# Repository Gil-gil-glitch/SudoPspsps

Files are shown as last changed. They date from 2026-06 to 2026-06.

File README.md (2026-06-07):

# SudoPsPsPs — Assistive Robot Cat

SudoPsPsPs is an assistive robotic cat designed to provide companionship and proactive social interaction. Using a pan-tilt head mechanism, computer vision (Intel RealSense D455), local speech processing, and a Liquid Foundation Model (LFM), the robot maintains attention on users and engages in meaningful, mood-aware conversations.

All interactions are driven by **vocal commands and natural conversation**, processed locally via Faster-Whisper, with heavy visual and LLM reasoning offloaded to a dedicated inference server.

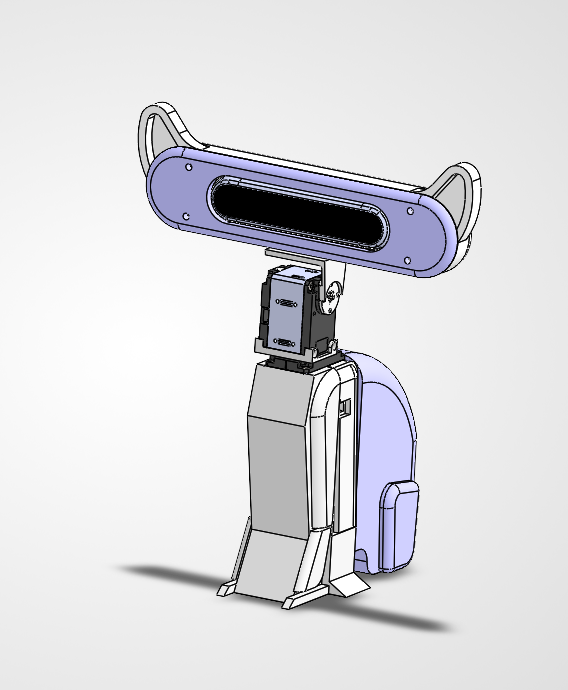
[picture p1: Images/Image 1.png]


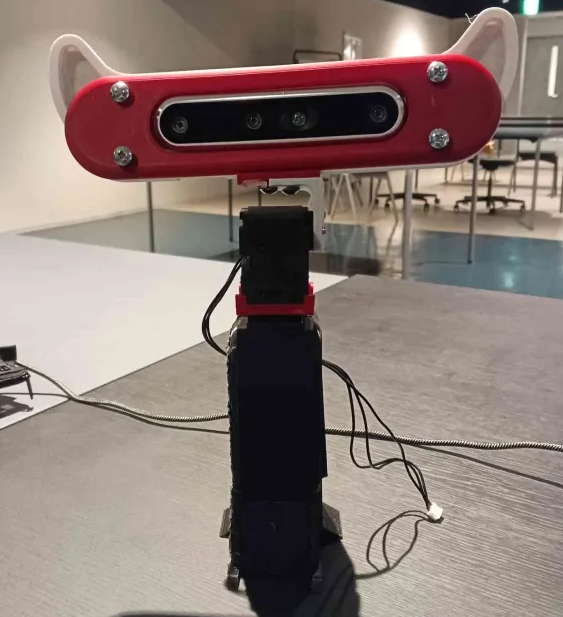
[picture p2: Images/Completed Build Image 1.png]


---

## Hardware

### Pan-Tilt Mechanism

| Component | Description |
|---|---|
| Pan Servo | Dynamixel XL430-W250-T (ID 1) |
| Tilt Servo | Dynamixel XL430-W250-T (ID 2) |
| Controller | OpenCR |
| Interface | USB Serial |
| Protocol | Dynamixel Protocol 2.0 |

### Sensor & Audio Suite

| Component | Details |
|---|---|
| Vision | Intel RealSense D455 |
| Microphone | Steinberg UR22mkII audio interface |
| Speaker | Local ALSA-routed speaker |

---

## Software Architecture

The system uses **ROS 2 (Humble)** as middleware connecting hardware control, perception, and reasoning. Two machines communicate over a dedicated Ethernet link.

| Machine | Role |
|---|---|
| **Macbook** (Inference Server) | Runs `model_server.py` and the LFM. Handles NLP, task scheduling reasoning, and vision-based VAD emotion inference. |
| **Lenovo LOQ** (Robot Host) | Runs all ROS 2 nodes. Handles hardware control (Dynamixels, RealSense), STT/TTS, image preprocessing, and the behavioral state machine. |
| **Ethernet `10.42.0.x`** | High-speed local link passing image crops and JSON payloads between the two machines. |

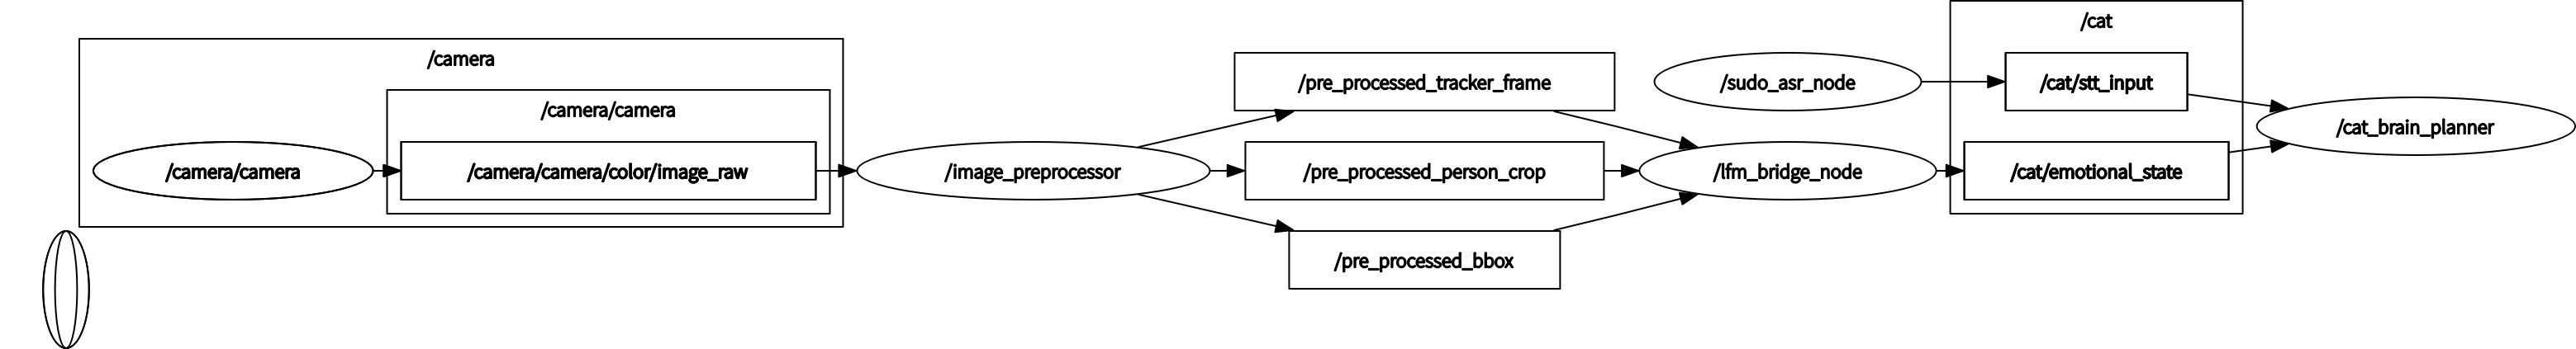
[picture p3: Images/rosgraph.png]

All the nodes, aside from cat_brain_planner and lfm_bridge_node, run on the Lenovo LOQ side while the cat_brain_planner and lfm_bridge_node acts as the interface to the Inference server hosted on the Macbook.

---

## Codebase Overview

### Hardware Control

- **`dynamixel_driver.py`** — OpenCR communication, torque enablement, and startup calibration. Converts degrees to raw Dynamixel 2.0 protocol positions.
- **`head_node.py`** — ROS 2 hardware abstraction node. Subscribes to `/head/pan_target` and `/head/tilt_target`; applies Exponential Moving Average (EMA) smoothing to motor commands.

### Vision & Tracking

- **`person_targetting_node.py`** — Core visual state machine (`SEARCHING` → `TRACKING` → `TALKING`). Uses MediaPipe Pose for bounding boxes and implements cat-like kinematics: discrete saccades, generous dead-zones, and curious idle head-tilts.
- **`image_preprocessor.py`** — Active only when locked onto a user. Crops and resizes RealSense frames (224×224 person crop, 336×336 spatial context) and publishes them for inference.

### Audio & Speech Processing

- **`stt_node.py`** — Local ASR via `faster-whisper` on GPU. Features an RMS noise threshold gate; publishes transcriptions to `/cat/stt_input`. This is the **primary trigger** for robot interaction.
- **`tts_node.py`** — Offline TTS using Piper. Subscribes to `/cat/robot_actions`, extracts `message_to_user` from JSON payloads, and routes audio to the local ALSA system.
- **`speaker_finder.py`** — PyAudio utility to enumerate hardware audio devices and identify the correct speaker index.

### AI & Reasoning

- **`lfm_bridge_node.py`** — Async bridge node. Packages cropped user images as base64 payloads and POSTs them to the Macbook vision model. Publishes Valence, Arousal, and Dominance (VAD) scores to `/cat/emotional_state`.
- **`cat_brain_planner.py`** — The cognitive core. Manages multi-turn conversation, schedule assignment, and proactive reminders. Fuses STT input with VAD emotional state to generate mood-aware suggestions (e.g., suggesting rest if valence is low).
- **`train_lora.py`** — Standalone QLoRA fine-tuning script for the LFM2 vision-language model using HuggingFace `peft` and `trl`. Aligns the robot's persona and reasoning with the Sudo dataset.

---

## Setup & Launch

### Network Configuration

Connect both machines over Ethernet and assign static IPs:

| Machine | IP |
|---|----|
| Macbook (Inference Server) | `10.42.0.2` |
| Lenovo LOQ (Robot Host) | `10.42.0.1` |

---

### 1. Macbook — Start the Inference Server

```bash
python model_server.py --host 0.0.0.0 --port 8000
```

---

### 2. Lenovo LOQ — Source the Workspace

```bash
source /opt/ros/humble/setup.bash
source ~/ri_one_master_ws/install/setup.bash
```

---

### 3. Launch Hardware Drivers

```bash
ros2 launch realsense2_camera rs_launch.py
ros2 run sudo_pspsps head_node
```

---

### 4. Spin Up Perception & Audio Nodes

Open separate terminals for each:

```bash
ros2 run sudo_pspsps person_targetting_node
ros2 run sudo_pspsps image_preprocessor
ros2 run sudo_pspsps stt_node
ros2 run sudo_pspsps tts_node
```

---

### 5. Start Bridging & Planning Nodes

```bash
ros2 run sudo_pspsps lfm_bridge_node
ros2 run sudo_pspsps cat_brain_planner
```

---

### Manual Head Test

To verify servo movement before launching the planner:

```bash
ros2 topic pub --once /head/pan_target std_msgs/msg/Float32 "{data: 30.0}"
```

---

## Current Status

| Feature | Status |
|---|---|
| Dynamixel communication & ROS 2 head node | Complete |
| Cat-like saccade motion profiling | Complete |
| MediaPipe person tracking & targeting | Complete |
| Local Whisper STT & Piper TTS | Complete |
| Async LFM HTTP bridging to Macbook | Complete |
| VAD emotional state assessment from RealSense crops | Complete |
| Conversational task planning & proactive mood suggestions | Complete |
| QLoRA training pipeline for LFM persona alignment | Complete |

---

## Team Vision

SudoPsPsPs aims to be a robotic companion capable of maintaining attention, understanding conversational context, and proactively checking in on users — not by reacting to physical triggers, but by acting as a supportive social presence guided by vocal input, multimodal perception, and advanced LLM reasoning.

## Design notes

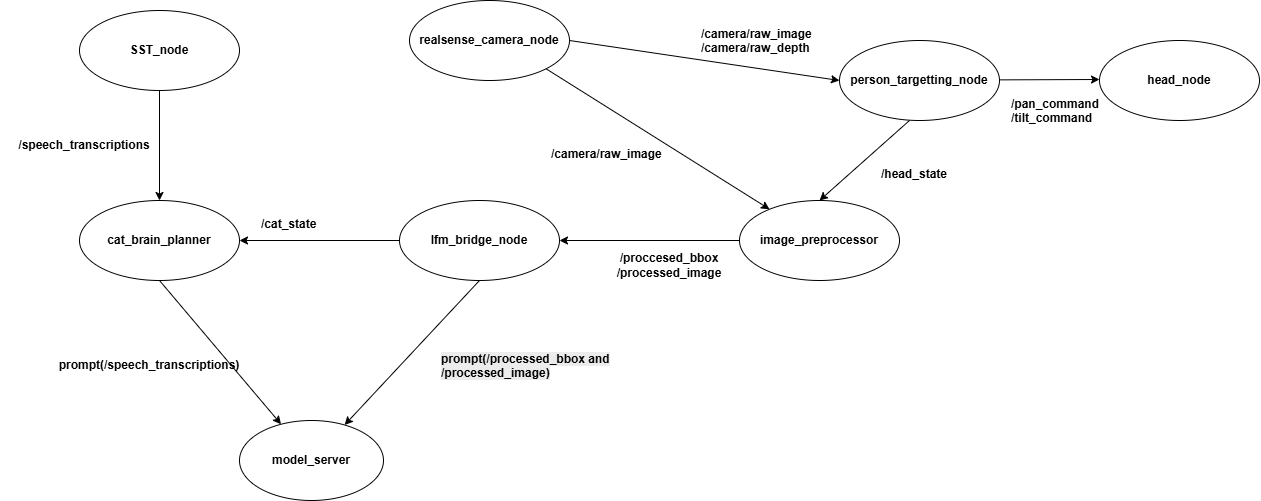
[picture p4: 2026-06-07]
Images/SudoPsPsPsArchitecture.drawio.png

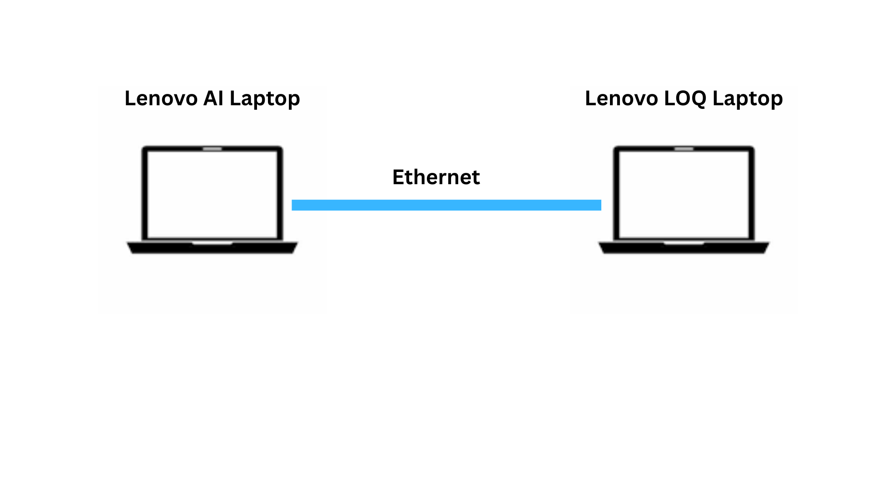
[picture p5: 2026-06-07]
Images/Communication Diagram.png

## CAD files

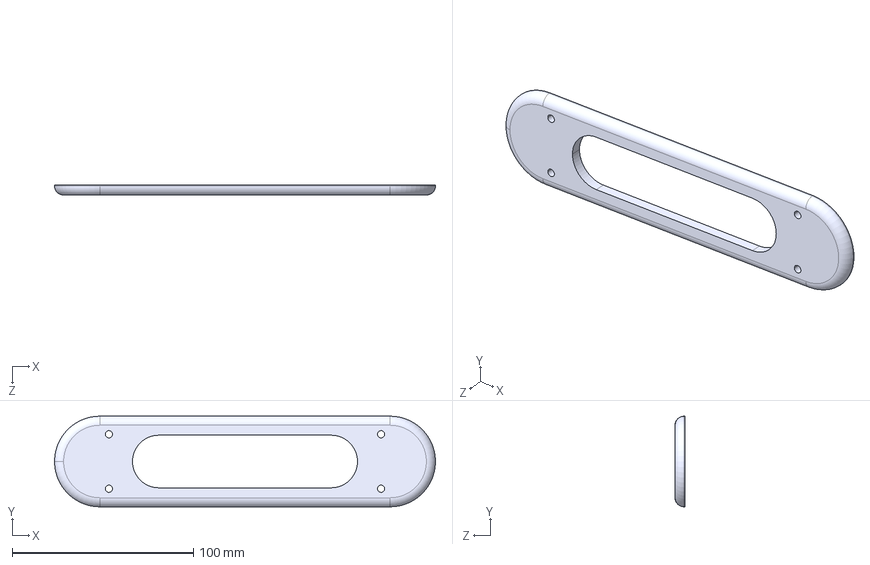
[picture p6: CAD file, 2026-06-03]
3d-Models/Step files/1. Head Front.STEP
210.0 x 50.0 x 5.50 mm

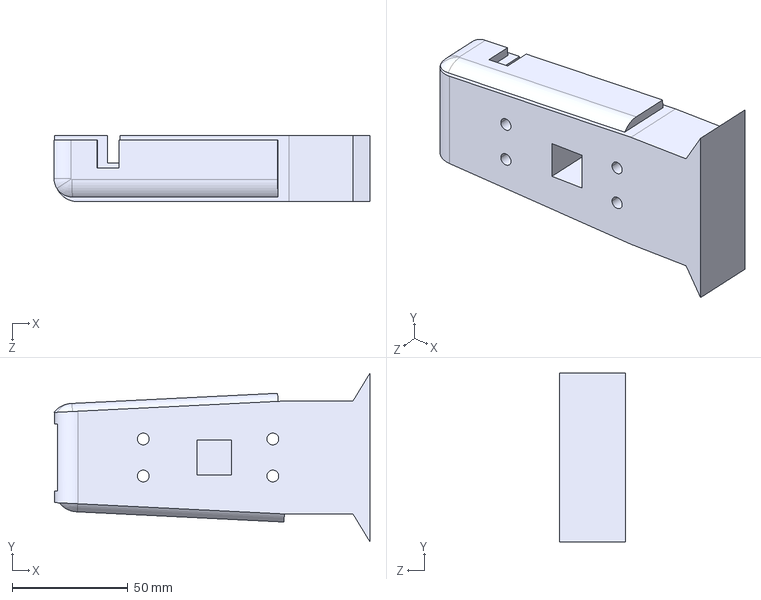
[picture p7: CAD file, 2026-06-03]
3d-Models/Step files/4. Body Back.STEP
136.6 x 73.0 x 28.6 mm

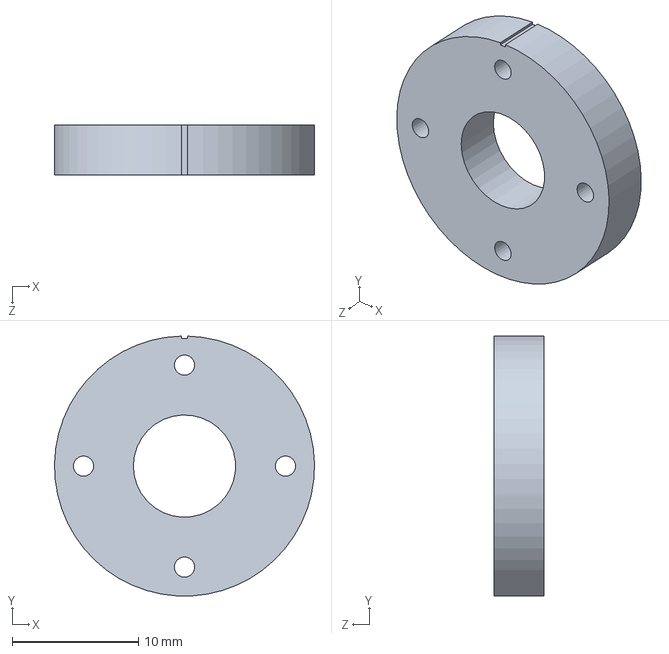
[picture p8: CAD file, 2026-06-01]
3d-Models/Solidworks/5. Neck.SLDPRT
20.6 x 20.6 x 4.00 mm

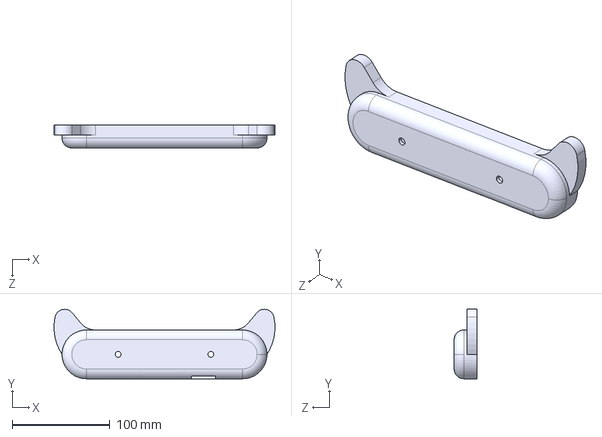
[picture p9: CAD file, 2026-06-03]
3d-Models/Step files/2. Head Back.STEP
226.5 x 71.3 x 23.4 mm

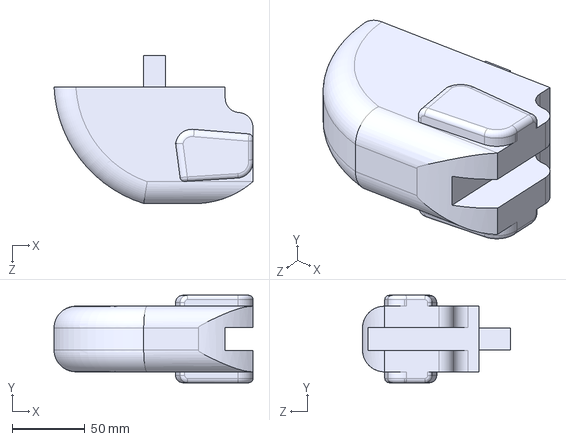
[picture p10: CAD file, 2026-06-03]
3d-Models/Step files/Tail End.STEP
136.4 x 60.0 x 101.5 mm

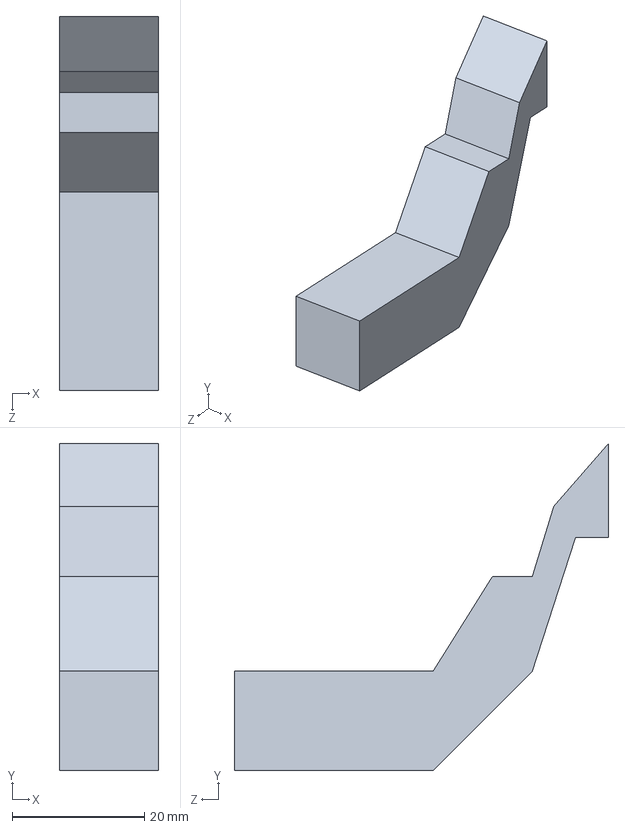
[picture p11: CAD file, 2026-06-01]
3d-Models/Solidworks/6. Tail.SLDPRT
15.0 x 49.4 x 56.5 mm

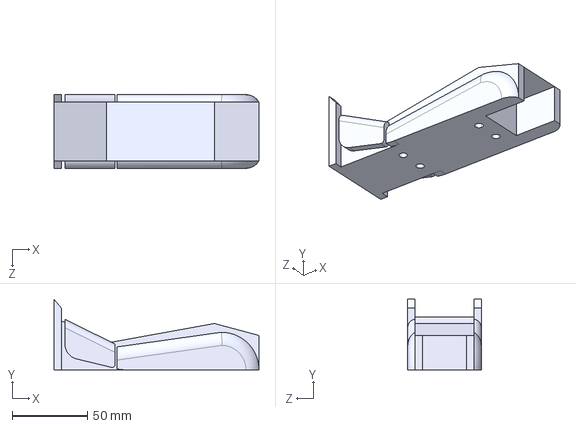
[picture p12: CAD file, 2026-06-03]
3d-Models/Step files/3. Body Front.STEP
136.3 x 47.0 x 49.0 mm

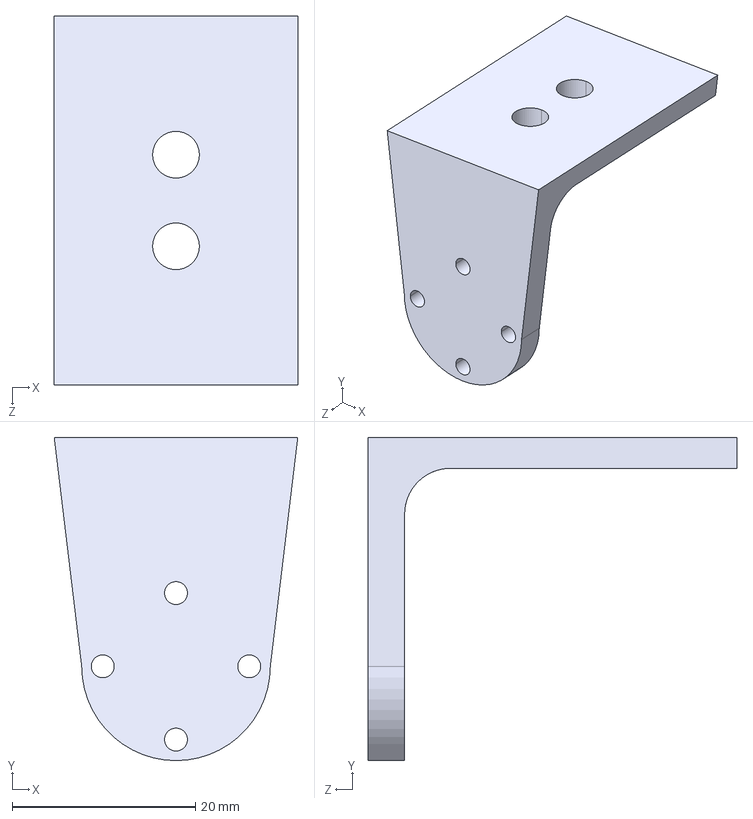
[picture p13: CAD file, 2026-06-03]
3d-Models/Step files/6. Top Motor Mount^Backv2.STEP
26.6 x 35.3 x 40.3 mm

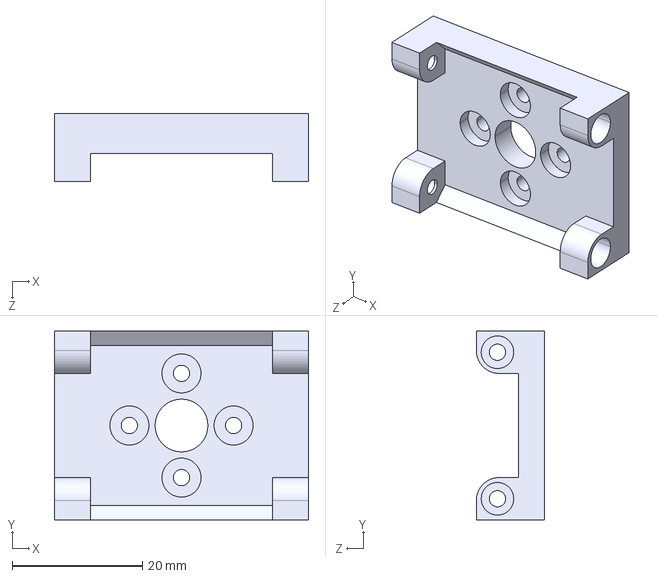
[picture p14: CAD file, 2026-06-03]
3d-Models/Step files/5. Bottom Motor Mount.STEP
39.0 x 29.0 x 10.5 mm

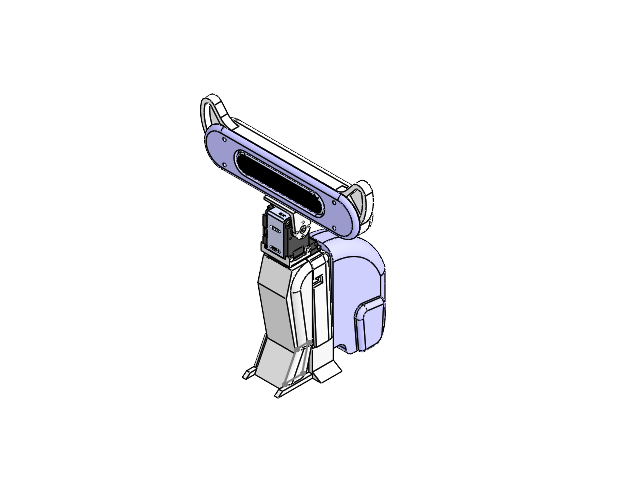
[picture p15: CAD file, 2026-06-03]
3d-Models/Solidworks/Full Body v2.SLDASM
XL430_W250_T x 2
3. Body Front
4. Body Back
Tail End
5. Bottom Motor Mount
6. Top Motor Mount^Back
Intel Realsense D455
1. Head Front
2. Head Back

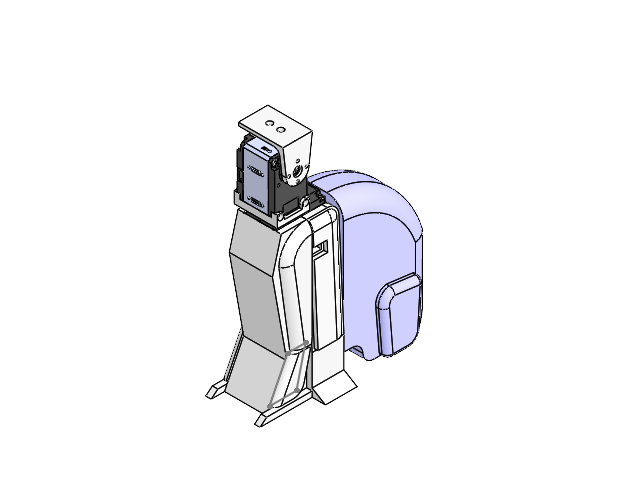
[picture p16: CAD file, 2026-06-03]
3d-Models/Solidworks/Back.SLDASM
XL430_W250_T x 2
3. Body Front
4. Body Back
Tail End
5. Bottom Motor Mount
6. Top Motor Mount^Back

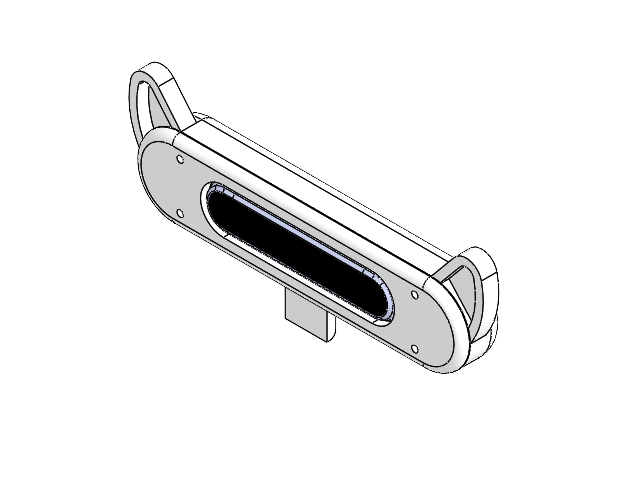
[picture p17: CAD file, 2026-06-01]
3d-Models/Solidworks/Head.SLDASM
Intel Realsense D455
1. Head Front
2. Head Back

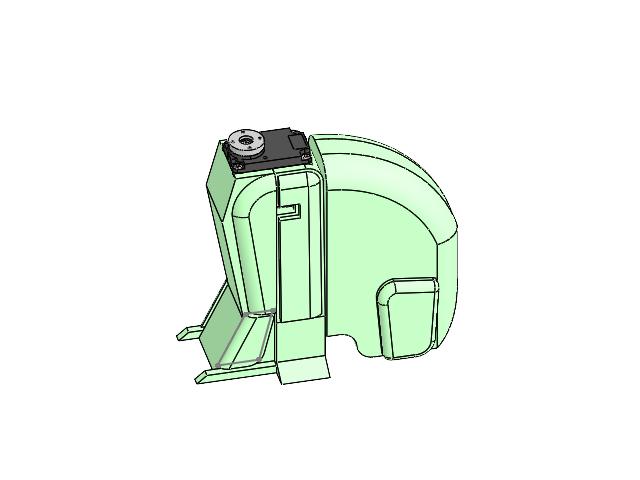
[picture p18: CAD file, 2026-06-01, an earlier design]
3d-Models/Solidworks/Full Body.SLDASM
Part4^Full Body
XL430_W250_T
3. Body Front
4. Body Back
Tail End
5. Neck

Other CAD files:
3d-Models/Step files/6. Top Motor Mount^Back.STEP
3d-Models/Solidworks/1. Head Front.SLDPRT
3d-Models/Solidworks/2. Head Back.SLDPRT
3d-Models/Solidworks/3. Body Front.SLDPRT
3d-Models/Solidworks/4. Body Back.SLDPRT
3d-Models/Solidworks/5. Bottom Motor Mount.SLDPRT

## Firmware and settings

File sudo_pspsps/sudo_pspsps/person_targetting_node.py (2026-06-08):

#
## person_targeting_node.py
#
#  Behaviour states (externally switchable via /head/behavior String topic):
#
#    SEARCHING  — No person committed yet.  Head makes slow deliberate cat-like
#                 glances (discrete saccades to a few look-points, not a sweep).
#                 Requires ACQUIRE_FRAMES consecutive detections before
#                 committing to TRACKING — prevents flickering on a single
#                 noisy frame.
#
#    TRACKING   — Locked onto the closest person.  Cat saccade+hold: only moves
#                 when the smoothed error exceeds a generous dead-zone, then
#                 snaps and freezes.  Occasional curious idle head-tilts.
#                 Only returns to SEARCHING after LOST_TIMEOUT_SEC of *zero*
#                 detections — brief MediaPipe dropouts are ignored.
#
#    TALKING    — Engaged with person.  Pan is nearly locked (only large
#                 corrections allowed).  Tilt nods gently and periodically.
#                 Occasional small curious tilts.  Falls back to SEARCHING
#                 only on sustained person-loss.
#
#  State-switch hysteresis
#  ───────────────────────
#  SEARCHING → TRACKING  requires ACQUIRE_FRAMES (~1s) of consecutive hits.
#                         Transition is triggered by the detection stream, not
#                         a timer.
#  TRACKING  → SEARCHING requires LOST_TIMEOUT_SEC of no detections, enforced
#                         exclusively by the watchdog — single-frame misses are
#                         ignored so brief MediaPipe dropouts don't break lock.
#  TALKING   → SEARCHING same lost-timeout watchdog rule.
#  TALKING   is only entered via the external /head/behavior topic; it is
#             never auto-transitioned into by this node.
#
#  Published topics
#  ────────────────
#  /head/pan_target   Float32  — commanded pan angle (degrees)
#  /head/tilt_target  Float32  — commanded tilt angle (degrees)
#  /head/state        String   — current state: "searching" | "tracking" | "talking"
#                                Latched (transient_local) so late subscribers
#                                get the last value immediately on connect.
#
#  Movement philosophy (cat-like)
#  ───────────────────────────────
#  • Moves are discrete saccades — snap, then hold completely still.
#  • Dead-zones are large so jitter never triggers movement.
#  • EMA smoothing on detections so landmark noise is absorbed before
#    any decision is made.
#  • Smoother never resets to None — decays toward centre when lost,
#    preventing the cold-start giant-saccade bug.
#

import math
import random
import numpy as np
import rclpy
from rclpy.node import Node
from rclpy.qos import (
    QoSProfile, ReliabilityPolicy, HistoryPolicy,
    DurabilityPolicy,
)
from sensor_msgs.msg import Image
from std_msgs.msg import Float32, String
from cv_bridge import CvBridge
import cv2
import mediapipe as mp
from mediapipe.tasks import python as mp_python
from mediapipe.tasks.python import vision as mp_vision
import urllib.request
import os
import tempfile

# ── MediaPipe model ────────────────────────────────────────────────────────────
_MODEL_URL = (
    "https://storage.googleapis.com/mediapipe-models/"
    "pose_landmarker/pose_landmarker_lite/float16/latest/"
    "pose_landmarker_lite.task"
)
_MODEL_PATH = os.path.join(tempfile.gettempdir(), "pose_landmarker_lite.task")

def _ensure_model() -> str:
    if not os.path.exists(_MODEL_PATH):
        print(f"[PersonTargetingNode] Downloading model → {_MODEL_PATH}")
        urllib.request.urlretrieve(_MODEL_URL, _MODEL_PATH)
    return _MODEL_PATH

# ── Behaviour names ────────────────────────────────────────────────────────────
BEHAVIOR_SEARCHING = "searching"
BEHAVIOR_TRACKING  = "tracking"
BEHAVIOR_TALKING   = "talking"

# ── Saccade sub-states ─────────────────────────────────────────────────────────
_HOLDING   = "holding"
_SACCADING = "saccading"


class PersonTargetingNode(Node):

    # ── Camera intrinsics — RealSense D455 ───────────────────────────────────
    # D455 colour sensor: 1280x800 native, 87x58 deg FOV.
    # If you stream at a lower resolution (e.g. 640x400) the FOV is identical;
    # only px_per_deg changes.  Update CAMERA_WIDTH/HEIGHT to match your
    # launch file — HFOV/VFOV stay fixed regardless of resolution.
    CAMERA_WIDTH  = 1280
    CAMERA_HEIGHT = 800
    HFOV = 87.0
    VFOV = 58.0


    # ── Motor direction signs ─────────────────────────────────────────────────
    # Set to +1 or -1 to match the physical installation.
    #
    # PAN_SIGN:  +1 = positive motor angle pans RIGHT (from the front).
    #            Flip to -1 if the head moves LEFT when the person is right.
    # TILT_SIGN: +1 = positive motor angle tilts UP.
    #            Flip to -1 if the head tilts DOWN when the person is above centre.
    #
    # Logs show the head moved the wrong way in pan, so PAN_SIGN = -1.
    # Verify TILT_SIGN by standing in front and moving up/down.
    PAN_SIGN  = -1
    TILT_SIGN =  1

    # ── Detection cadence ─────────────────────────────────────────────────────
    PROCESS_EVERY_N_FRAMES = 3        # ~10 Hz at 30 fps

    # ── EMA smoothing ─────────────────────────────────────────────────────────
    # Slower alpha (0.15) means ~7 frames to absorb a position jump —
    # keeps landmark jitter from ever reaching the saccade trigger.
    EMA_ALPHA       = 0.15
    EMA_DECAY_ALPHA = 0.03            # gentle centre-drift when no person

    # ── State-switch hysteresis ───────────────────────────────────────────────
    # Must see this many *consecutive* detection frames before switching
    # SEARCHING → TRACKING.  At ~10 Hz, 10 frames ≈ 1.0 s of stable detection.
    ACQUIRE_FRAMES   = 10

    # Must lose the person for this many seconds before switching back to
    # SEARCHING.  6 s tolerates brief occlusions / pose-detector dropouts.
    LOST_TIMEOUT_SEC = 6.0

    # ── Saccade thresholds ────────────────────────────────────────────────────
    # TRACKING dead-zone is generous — a still person standing in frame
    # should produce near-zero movement.
    TRACKING_SACCADE_TRIGGER_DEG = 12.0
    TRACKING_SETTLE_DEG          =  3.0
    TRACKING_MIN_HOLD_SEC        =  3  # freeze after each saccade

    # TALKING pan corrections are rare — only large misalignments get fixed.
    TALKING_PAN_TRIGGER_DEG  = 15.0
    TALKING_MIN_HOLD_SEC     =  2.0

    # ── SEARCHING glance targets (pan °, tilt °) ──────────────────────────────
    SEARCH_GLANCE_POSITIONS = [
        ( 0.0, -3.0),   # centre
        (+60.0, -3.0),  # right
        ( 0.0, -3.0),   # centre
        (-60.0, -3.0),  # left
    ]
    SEARCH_HOLD_SEC         = 2.2     # seconds to dwell at each glance
    SEARCH_SACCADE_SPEED    = 40.0    # °/s during the glance movement itself

    # ── TRACKING idle tilt ────────────────────────────────────────────────────
    IDLE_TILT_INTERVAL_SEC    =  6.0
    IDLE_TILT_INTERVAL_JITTER =  2.5
    IDLE_TILT_MAG_DEG_SIGMA   =  3.0
    IDLE_TILT_MAG_MAX_DEG     =  5.0

    # ── TALKING motion ────────────────────────────────────────────────────────
    TALKING_NOD_AMP_DEG      =  2.5
    TALKING_NOD_PERIOD_SEC   =  3.8
    TALKING_TILT_INTERVAL_SEC    = 8.0
    TALKING_TILT_INTERVAL_JITTER = 3.0

    # ── Depth sampling ────────────────────────────────────────────────────────
    DEPTH_BBOX_SHRINK = 0.2
    DEPTH_MIN_MM      = 200
    DEPTH_MAX_MM      = 8000

    # ─────────────────────────────────────────────────────────────────────────

    def __init__(self):
        super().__init__('person_targeting_node')

        self._bridge        = CvBridge()
        self._frame_counter = 0
        self._latest_depth  = None

        self._px_per_deg_h = self.CAMERA_WIDTH  / self.HFOV
        self._px_per_deg_v = self.CAMERA_HEIGHT / self.VFOV
        self._cx = self.CAMERA_WIDTH  / 2.0
        self._cy = self.CAMERA_HEIGHT / 2.0

        # ── EMA — always alive, initialised to image centre ───────────────────
        self._smooth_px = self._cx
        self._smooth_py = self._cy

        # ── Detection state ───────────────────────────────────────────────────
        # _person_visible is ONLY cleared by the watchdog, not by individual
        # missed frames.  This makes TRACKING robust to brief dropout frames.
        # _consecutive_misses counts unbroken miss-frames for the watchdog to
        # use as a secondary signal alongside wall-clock time.
        self._person_visible      = False
        self._last_detection_time = None   # rclpy.Time of last positive frame

        # ── Acquisition counter (hysteresis into TRACKING) ────────────────────
        self._acquire_count = 0

        # ── Published gaze ────────────────────────────────────────────────────
        self._gaze_pan  = 0.0
        self._gaze_tilt = 0.0

        # ── Saccade sub-state (shared by TRACKING & TALKING) ──────────────────
        self._saccade_state = _HOLDING
        self._hold_until    = None        # float seconds
        self._saccade_timeout = None        # rclpy.Time when a saccade should be considered failed if not settled


        # ── Idle / curious tilt ───────────────────────────────────────────────
        self._idle_tilt_offset    = 0.0
        self._next_idle_tilt_time = None

        # ── Top-level behaviour ────────────────────────────────────────────────
        self._behavior = BEHAVIOR_SEARCHING

        # ── Searching glance state ─────────────────────────────────────────────
        self._search_glance_idx   = 0
        self._search_glance_until = None

        # ── Talking clock ─────────────────────────────────────────────────────
        self._talking_start_sec = None

        # ── MediaPipe ─────────────────────────────────────────────────────────
        model_path = _ensure_model()
        base_opts  = mp_python.BaseOptions(model_asset_path=model_path)
        pose_opts  = mp_vision.PoseLandmarkerOptions(
            base_options=base_opts,
            running_mode=mp_vision.RunningMode.IMAGE,
            num_poses=4,
            min_pose_detection_confidence=0.5,
            min_pose_presence_confidence=0.5,
            min_tracking_confidence=0.5,
        )
        self._landmarker = mp_vision.PoseLandmarker.create_from_options(pose_opts)

        sensor_qos = QoSProfile(
            reliability=ReliabilityPolicy.BEST_EFFORT,
            history=HistoryPolicy.KEEP_LAST,
            depth=1,
        )

        # Latched QoS for /head/state so late subscribers (e.g. ImagePreprocessor)
        # immediately receive the current state on connect.
        latched_qos = QoSProfile(
            reliability=ReliabilityPolicy.RELIABLE,
            history=HistoryPolicy.KEEP_LAST,
            depth=1,
            durability=DurabilityPolicy.TRANSIENT_LOCAL,
        )

        self.create_subscription(
            Image, '/camera/camera/color/image_raw',
            self._image_callback, sensor_qos,
        )
        self.create_subscription(
            Image, '/camera/camera/depth/image_rect_raw',
            self._depth_callback, sensor_qos,
        )
        self.create_subscription(
            String, '/head/behavior',
            self._behavior_callback, 10,
        )

        self._pan_pub   = self.create_publisher(Float32, '/head/pan_target',  10)
        self._tilt_pub  = self.create_publisher(Float32, '/head/tilt_target', 10)
        self._state_pub = self.create_publisher(String,  '/head/state', latched_qos)

        self.create_timer(0.05, self._motion_tick)   # 20 Hz
        self.create_timer(0.5,  self._watchdog)

        # Kick off the SEARCHING state properly on the first spin iteration.
        # We use a one-shot timer (cancelled inside the callback) rather than
        # calling _enter_searching() directly here because get_clock().now()
        # returns 0 during __init__ in some RMW implementations — the timer
        # fires after the node is fully initialised and the clock is live.
        self._startup_done = False

        self.get_logger().info(
            "PersonTargetingNode ready  "
            f"acquire={self.ACQUIRE_FRAMES} frames  "
            f"lost_timeout={self.LOST_TIMEOUT_SEC}s  "
            f"track_trigger={self.TRACKING_SACCADE_TRIGGER_DEG}°  "
            f"hold={self.TRACKING_MIN_HOLD_SEC}s"
        )

    # ── State publisher ───────────────────────────────────────────────────────

    def _publish_state(self):
        msg = String()
        msg.data = self._behavior
        self._state_pub.publish(msg)

    def _transition_to(self, new_behavior: str, now_sec: float):
        """
        Central choke-point for all state transitions.
        Logs the edge, updates _behavior, calls the enter-hook, and
        publishes /head/state.  All callers must go through here.
        """
        if new_behavior == self._behavior:
            return
        self.get_logger().info(
            f"STATE  {self._behavior.upper()} → {new_behavior.upper()}"
        )
        self._behavior = new_behavior
        if new_behavior == BEHAVIOR_SEARCHING:
            self._enter_searching(now_sec)
        elif new_behavior == BEHAVIOR_TRACKING:
            self._enter_tracking(now_sec, fresh=True)
        elif new_behavior == BEHAVIOR_TALKING:
            self._enter_talking(now_sec)
        self._publish_state()

    # ── External behavior override ────────────────────────────────────────────

    def _behavior_callback(self, msg: String):
        requested = msg.data.strip().lower()
        if requested not in (BEHAVIOR_SEARCHING, BEHAVIOR_TRACKING, BEHAVIOR_TALKING):
            self.get_logger().warn(f"Unknown behavior '{requested}' — ignoring.")
            return
        now_sec = self.get_clock().now().nanoseconds / 1e9
        self._transition_to(requested, now_sec)

    # ── Depth callback ────────────────────────────────────────────────────────

    def _depth_callback(self, msg: Image):
        self._latest_depth = self._bridge.imgmsg_to_cv2(
            msg, desired_encoding='passthrough'
        )

    # ── Image callback ────────────────────────────────────────────────────────

    def _image_callback(self, msg: Image):
        self._frame_counter += 1
        if self._frame_counter % self.PROCESS_EVERY_N_FRAMES != 0:
            return

        cv_image  = self._bridge.imgmsg_to_cv2(msg, desired_encoding='bgr8')
        rgb_image = cv2.cvtColor(cv_image, cv2.COLOR_BGR2RGB)
        h, w      = cv_image.shape[:2]

        mp_image = mp.Image(image_format=mp.ImageFormat.SRGB, data=rgb_image)
        results  = self._landmarker.detect(mp_image)

        if not results.pose_landmarks:
            # Decay smoother toward centre — prevents cold-start saccade jump.
            # Do NOT clear _person_visible here — that is the watchdog's job.
            # Resetting it per-frame would cause TRACKING to stutter on every
            # brief MediaPipe miss.
            self._smooth_px += self.EMA_DECAY_ALPHA * (self._cx - self._smooth_px)
            self._smooth_py += self.EMA_DECAY_ALPHA * (self._cy - self._smooth_py)
            self._acquire_count = 0   # reset acquisition streak on any miss
            return

        # ── Build bboxes ──────────────────────────────────────────────────────
        # Minimum area filter: a real person at reasonable range occupies at
        # least ~2% of the frame area.  Tiny landmark clusters on wall textures
        # or furniture are rejected here before ever reaching the acquisition
        # counter, preventing false SEARCHING → TRACKING transitions.
        MIN_PERSON_AREA_FRAC = 0.02
        min_area = w * h * MIN_PERSON_AREA_FRAC

        persons = []
        for landmarks in results.pose_landmarks:
            xs = [int(lm.x * w) for lm in landmarks]
            ys = [int(lm.y * h) for lm in landmarks]
            xmin = max(0, min(xs) - 20)
            xmax = min(w, max(xs) + 20)
            ymin = max(0, min(ys) - 20)
            ymax = min(h, max(ys) + 20)
            bbox_area = (xmax - xmin) * (ymax - ymin)
            if xmax > xmin and ymax > ymin and bbox_area >= min_area:
                persons.append((xmin, ymin, xmax, ymax))

        if not persons:
            self._acquire_count = 0   # landmarks present but all degenerate boxes
            return

        # ── Update EMA with closest-person centre ─────────────────────────────
        xmin, ymin, xmax, ymax = self._closest_person(persons)
        raw_px = (xmin + xmax) / 2.0
        raw_py = (ymin + ymax) / 2.0

        a = self.EMA_ALPHA
        self._smooth_px = a * raw_px + (1.0 - a) * self._smooth_px
        self._smooth_py = a * raw_py + (1.0 - a) * self._smooth_py

        was_visible               = self._person_visible
        self._person_visible      = True
        self._last_detection_time = self.get_clock().now()

        now_sec = self.get_clock().now().nanoseconds / 1e9

        if self._behavior == BEHAVIOR_SEARCHING:
            # ── SEARCHING: accumulate consecutive hits before committing ───────
            self._acquire_count += 1
            if self._acquire_count >= self.ACQUIRE_FRAMES:
                self.get_logger().info(
                    f"Person acquired ({self.ACQUIRE_FRAMES} consecutive frames) "
                    "— SEARCHING → TRACKING"
                )
                self._transition_to(BEHAVIOR_TRACKING, now_sec)
        else:
            # ── TRACKING / TALKING: re-acquisition hold after a dropout ────────
            if not was_visible:
                # EMA needs a few frames to warm up after being invisible —
                # hold before allowing any saccade.
                self._hold_until = now_sec + self.TRACKING_MIN_HOLD_SEC

    # ── 20 Hz motion tick ─────────────────────────────────────────────────────

    def _motion_tick(self):
        now_sec = self.get_clock().now().nanoseconds / 1e9

        # First tick after node is fully live: kick off the SEARCHING glance
        # sequence.  We do this here rather than in __init__ because
        # get_clock().now() can return 0 during construction.
        if not self._startup_done:
            self._startup_done = True
            self._enter_searching(now_sec)
            self._publish_state()

        if self._behavior == BEHAVIOR_SEARCHING:
            self._tick_searching(now_sec)
        elif self._behavior == BEHAVIOR_TRACKING:
            self._tick_tracking(now_sec)
        elif self._behavior == BEHAVIOR_TALKING:
            self._tick_talking(now_sec)

    # ── SEARCHING ─────────────────────────────────────────────────────────────

    def _enter_searching(self, now_sec: float):
        self._acquire_count       = 0
        self._person_visible      = False   # safe to reset here: we're leaving lock
        self._search_glance_idx   = 0
        self._search_glance_until = now_sec + self.SEARCH_HOLD_SEC
        self._saccade_state       = _SACCADING
        self._idle_tilt_offset    = 0.0
        pan, tilt = self.SEARCH_GLANCE_POSITIONS[0]
        self._saccade_to(pan, tilt)
        self.get_logger().info(
            f"SEARCHING — glance[0] ({pan:+.0f}°, {tilt:+.0f}°)"
        )

    def _tick_searching(self, now_sec: float):
        if self._search_glance_until is None:
            return
        if now_sec < self._search_glance_until:
            return   # still dwelling — don't move

        self._search_glance_idx = (
            (self._search_glance_idx + 1) % len(self.SEARCH_GLANCE_POSITIONS)
        )
        pan, tilt = self.SEARCH_GLANCE_POSITIONS[self._search_glance_idx]
        self._saccade_to(pan, tilt)
        self._search_glance_until = now_sec + self.SEARCH_HOLD_SEC
        self.get_logger().info(
            f"SEARCHING — glance[{self._search_glance_idx}] "
            f"({pan:+.0f}°, {tilt:+.0f}°)"
        )

    # ── TRACKING ──────────────────────────────────────────────────────────────

    def _enter_tracking(self, now_sec: float, fresh: bool = False):
        self._saccade_state    = _HOLDING
        self._idle_tilt_offset = 0.0
        self._hold_until       = now_sec + self.TRACKING_MIN_HOLD_SEC
        self._saccade_timeout  = None
        self._schedule_next_idle_tilt(now_sec)

    def _tick_tracking(self, now_sec: float):
        if not self._person_visible:
            return

        pan_err, tilt_err, total_err = self._gaze_error()

        if self._saccade_state == _HOLDING:
            hold_expired = (self._hold_until is None or now_sec >= self._hold_until)
            if hold_expired and total_err > self.TRACKING_SACCADE_TRIGGER_DEG:
                target_pan, target_tilt, _ = self._target_angles()
                self.get_logger().info(
                    f"[TRACKING SACCADE] err={total_err:.1f}°  "
                    f"target=({target_pan:+.1f}°, {target_tilt:+.1f}°)"
                )
                self._idle_tilt_offset = 0.0
                self._schedule_next_idle_tilt(now_sec)
                self._saccade_to(target_pan, target_tilt + self._idle_tilt_offset)
                
                self._saccade_state = _SACCADING
                # Allow 1.5 seconds for the smoothed head to physically reach the target
                self._saccade_timeout = now_sec + 1.5
            else:
                self._maybe_idle_tilt(now_sec)
            return

        # SACCADING — Wait for head to physically settle.
        # DO NOT re-issue _saccade_to() here! _gaze_pan is the commanded target;
        # adding current visual error to it while the head is moving causes runaway feedback.
        settled = total_err <= self.TRACKING_SETTLE_DEG
        timed_out = self._saccade_timeout is not None and now_sec >= self._saccade_timeout
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

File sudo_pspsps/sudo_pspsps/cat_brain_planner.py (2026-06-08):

import rclpy
from rclpy.node import Node
from std_msgs.msg import String
import json
import time
import re
import requests
from datetime import datetime

# ─────────────────────────────────────────────
#  CONFIG  — set to laptop A's ethernet IP
# ─────────────────────────────────────────────
INFERENCE_SERVER = "http://10.42.0.2:8000"

# SYSTEM_PROMPT removed — it now lives in model_server.py (DEFAULT_SYSTEM_PROMPT).
# Keeping it here and re-transmitting it on every request was the main driver of
# the MPS OOM crash (larger tokenisation → larger intermediate buffers → 17 GB
# Metal allocation failure).  The server falls back to its built-in prompt when
# system_prompt is omitted from the request body.
#
# The intervention-gate call below still sends its own one-off system prompt
# because it needs a different JSON schema ({should_intervene, reason}).

# ─────────────────────────────────────────────
#  HELPERS
# ─────────────────────────────────────────────
def parse_llm_json(raw: str) -> dict:
    """Robustly extract JSON from LLM output."""
    raw = re.sub(r"```(?:json)?", "", raw).strip("`").strip()
    match = re.search(r"\{.*\}", raw, re.DOTALL)
    if match:
        try:
            return json.loads(match.group())
        except json.JSONDecodeError:
            pass
    return {
        "action": "CHAT",
        "reasoning": "parse_error",
        "message_to_user": "Sorry, I got a bit confused. Could you repeat that?"
    }


def minutes_until(event_time_str: str) -> float | None:
    """Return minutes until an event given 'HH:MM' string, or None if unparseable."""
    try:
        now = datetime.now()
        t = datetime.strptime(event_time_str, "%H:%M").replace(
            year=now.year, month=now.month, day=now.day
        )
        delta = (t - now).total_seconds() / 60.0
        return delta
    except Exception:
        return None


def build_mood_context(mood: dict) -> str:
    """Build a rich mood context string from VAD + visual rationale."""
    v, a, d = mood.get("vad", [5.0, 5.0, 5.0])
    rationale = mood.get("rationale", "No visual context available.")
    return (
        f"Visual observation from camera: '{rationale}'. "
        f"Emotion scores — valence: {v:.1f}/10, arousal: {a:.1f}/10, dominance: {d:.1f}/10. "
        "The visual observation takes priority if it conflicts with the scores."
    )


# ─────────────────────────────────────────────
#  NODE
# ─────────────────────────────────────────────
class CatBrainPlanner(Node):
    """
    Sudo – the Cat Brain Planner.

    Features
    --------
    1. Idle chit-chat that references the user's emotional state + visual context.
    2. Multi-turn schedule assignment (name → time → date loop until complete).
    3. Proactive reminders when a meeting is ~5 min away.
    4. Mood-aware suggestions: postpone task → play music (max 2), then 10-min back-off.
    """

    REMINDER_THRESHOLD_MIN      = 5.0
    REMINDER_CHECK_INTERVAL_SEC = 30.0
    BACKOFF_DURATION_SEC        = 10 * 60  # 10 minutes
    MAX_SUGGESTIONS             = 2        # postpone + music, then back off
    INTERVENE_VALENCE_GATE      = 4.5      # cheap pre-filter before LLM intervention check

    def __init__(self):
        super().__init__("cat_brain_planner")

        # ── Verify server reachable ───────────────────────────────────────
        self.get_logger().info(f"Checking inference server at {INFERENCE_SERVER}...")
        try:
            r = requests.get(f"{INFERENCE_SERVER}/health", timeout=5.0)
            if r.status_code == 200:
                self.get_logger().info("Inference server reachable ✓")
            else:
                self.get_logger().warn(f"Server responded with {r.status_code}")
        except Exception as e:
            self.get_logger().warn(f"Could not reach server: {e} — will retry on each call")

        # ── Emotional State ───────────────────────────────────────────────
        self.latest_mood: dict = {"vad": [5.0, 5.0, 5.0], "rationale": "Neutral"}

        # ── Schedule Store ────────────────────────────────────────────────
        self.schedule: list[dict] = []

        # ── Active Task-Creation Session ──────────────────────────────────
        self.active_task_draft: dict | None = None

        # ── Reminder Tracking ─────────────────────────────────────────────
        self.reminded_tasks: set = set()

        # ── Proactive Suggestion State ────────────────────────────────────
        self.last_suggestion_time: float = 0.0
        self.suggestion_count: int = 0
        self.waiting_for_suggestion_response: bool = False

        # ── ROS2 Pub/Sub ──────────────────────────────────────────────────
        self.create_subscription(String, "/cat/emotional_state", self.emotion_callback, 10)
        self.create_subscription(String, "/cat/stt_input",       self.stt_callback,     10)
        self.action_pub = self.create_publisher(String, "/cat/robot_actions", 10)

        # ── Reminder Timer ────────────────────────────────────────────────
        self.create_timer(self.REMINDER_CHECK_INTERVAL_SEC, self.reminder_tick)

        self.get_logger().info("CatBrainPlanner node started ✓")

    # ─────────────────────────────────────────────────────────────────────
    #  LLM WRAPPER  — now just an HTTP call
    # ─────────────────────────────────────────────────────────────────────
    def run_llm(self, user_prompt: str, system_prompt: str | None = None) -> dict:
        """Call the inference server.

        system_prompt is optional — omit it to use the server's built-in
        DEFAULT_SYSTEM_PROMPT (the normal Sudo persona).  Pass an explicit
        value only when you need a different response schema, e.g. the
        intervention-gate check that returns {should_intervene, reason}.
        """
        payload: dict = {"user_prompt": user_prompt}
        if system_prompt is not None:
            payload["system_prompt"] = system_prompt

        try:
            resp = requests.post(
                f"{INFERENCE_SERVER}/infer",
                json=payload,
                timeout=30.0,
            )
            resp.raise_for_status()
            raw = resp.json()["result"]
            return parse_llm_json(raw)
        except requests.Timeout:
            self.get_logger().error("Inference server timed out")
        except Exception as e:
            self.get_logger().error(f"Inference server error: {e}")
        return {
            "action": "CHAT",
            "reasoning": "server_error",
            "message_to_user": "Sorry, I'm having trouble thinking right now — give me a moment."
        }

    def publish(self, response: dict):
        self.action_pub.publish(String(data=json.dumps(response)))
        self.get_logger().info(f"→ {response['action']}: {response['message_to_user']}")
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

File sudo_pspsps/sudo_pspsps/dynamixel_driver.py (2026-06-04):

#
## dynamixel_driver.py
#
#  Driver for the Dynamixel pan-tilt mechanism on the cat head.
#

from dynamixel_sdk import PortHandler, PacketHandler
import time

# XL430 Control Table Addresses
ADDR_TORQUE_ENABLE = 64
ADDR_GOAL_POSITION = 116
ADDR_PRESENT_POSITION = 132

TORQUE_ENABLE = 1
TORQUE_DISABLE = 0

PROTOCOL_VERSION = 2.0

TICKS_PER_DEGREE = 4095.0 / 360.0


class DynamixelDriver:

    def __init__(
        self,
        device_name="/dev/ttyACM0",
        baudrate=1000000,
        pan_id=1,
        tilt_id=2,
    ):

        self.pan_id = pan_id
        self.tilt_id = tilt_id

        self.port_handler = PortHandler(device_name)
        self.packet_handler = PacketHandler(PROTOCOL_VERSION)

        if not self.port_handler.openPort():
            raise RuntimeError(
                f"Failed to open port {device_name}"
            )

        if not self.port_handler.setBaudRate(baudrate):
            raise RuntimeError(
                f"Failed to set baudrate {baudrate}"
            )

        print(f"Connected to {device_name}")

        self.pan_zero = 0
        self.tilt_zero = 0

    # Communication Helpers
    def ping(self, dxl_id):

        model, comm_result, error = (
            self.packet_handler.ping(
                self.port_handler,
                dxl_id
            )
        )

        print(
            f"PING ID={dxl_id} "
            f"MODEL={model} "
            f"COMM={comm_result} "
            f"ERROR={error}"
        )

        return comm_result == 0

    # Torque
    def enable_torque(self, dxl_id):

        comm_result, error = (
            self.packet_handler.write1ByteTxRx(
                self.port_handler,
                dxl_id,
                ADDR_TORQUE_ENABLE,
                TORQUE_ENABLE,
            )
        )

        print(
            f"Enable Torque ID={dxl_id} "
            f"COMM={comm_result} "
            f"ERROR={error}"
        )

    def disable_torque(self, dxl_id):

        self.packet_handler.write1ByteTxRx(
            self.port_handler,
            dxl_id,
            ADDR_TORQUE_ENABLE,
            TORQUE_DISABLE,
        )

    def enable(self):

        self.enable_torque(self.pan_id)
        self.enable_torque(self.tilt_id)

    def disable(self):

        self.disable_torque(self.pan_id)
        self.disable_torque(self.tilt_id)

    # Raw Position Access
    def read_position(self, dxl_id):

        position, comm_result, error = (
            self.packet_handler.read4ByteTxRx(
                self.port_handler,
                dxl_id,
                ADDR_PRESENT_POSITION,
            )
        )

        if comm_result != 0:
            print(
                f"Read Error ID={dxl_id} "
                f"COMM={comm_result}"
            )

        return position

    def write_position(self, dxl_id, position):

        comm_result, error = (
            self.packet_handler.write4ByteTxRx(
                self.port_handler,
                dxl_id,
                ADDR_GOAL_POSITION,
                int(position),
            )
        )

        #print(
        #    f"Write ID={dxl_id} "
        #    f"POS={position} "
        #    f"COMM={comm_result} "
        #    f"ERROR={error}"
        #)

    # Calibration
    def calibrate_zero(self):

        self.pan_zero = self.read_position(
            self.pan_id
        )

        self.tilt_zero = self.read_position(
            self.tilt_id
        )
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

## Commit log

2026-06-01 Added 3d-Models folder
    [1. Head Front.SLDPRT, 2. Head Back.SLDPRT, 3. Body Front.SLDPRT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]
2026-06-03 Updated the Solidworks files
    [1. Head Front.SLDPRT, 2. Head Back.SLDPRT, 3. Body Front.SLDPRT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]
2026-06-03 Added Step files
    [1. Head Front.STEP, 2. Head Back.STEP, 3. Body Front.STEP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]
2026-06-04 Added ROS2 interfaces and Dynamixel Drivers
2026-06-04 Revise README for SudoPsPsPs project
    Updated project name and expanded overview with detailed descriptions of hardware, software architecture, implemented components, current status, development roadmap, and quick start instructions.
2026-06-04 Restore and update README.md with project details
    Restored and updated the README.md file to include project overview, hardware details, software architecture, implemented components, current status, development roadmap, quick start instructions, an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
2026-06-06 Fix MPS kernel bug by routing inference to CPU
    Updated inference device handling to avoid MPS kernel bug and improved tokenization process. Adjusted comments for clarity on model behavior during generation.
2026-06-06 Implement context manager for device management during inference
    Added context manager to handle model device switching for inference, addressing MPS kernel bug.
2026-06-06 Refactor model device handling for stability
    Removed context manager for temporary model device switching and adjusted model loading for stable inference.
2026-06-07 Revise and restore README.md with project details
    Restored and updated the README.md file with project details, hardware specifications, software architecture, implemented components, current status, development roadmap, quick start instructions, an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
2026-06-07 Revise README with updated project details
    Updated README to reflect current project status and architecture.
2026-06-08 Revise README for updated project details
    Updated README to reflect new hardware and software architecture, including detailed descriptions of components and current status.
